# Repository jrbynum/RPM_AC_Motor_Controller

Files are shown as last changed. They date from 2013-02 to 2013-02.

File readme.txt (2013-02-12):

RPM AC Motor Controller

This is an Arduino based motor controller that uses a reflective optical sensor to calculate rpm and an LM135
to compute temperature. It uses the PID library to compute feedback. RPM and Temperature are displayed on an LCD. 

A zero crossing circuit and triac are used to control the set RPM which is based upon a 10K pot. The circuit 
can also be controlled using a pwm input. This input could be used from Mach3.

11/02/2013 - Added an Eagle Schematic and Board layout for an Arduino shield that will be used for development.

Rusty Bynum
jrbynum@shaw.ca

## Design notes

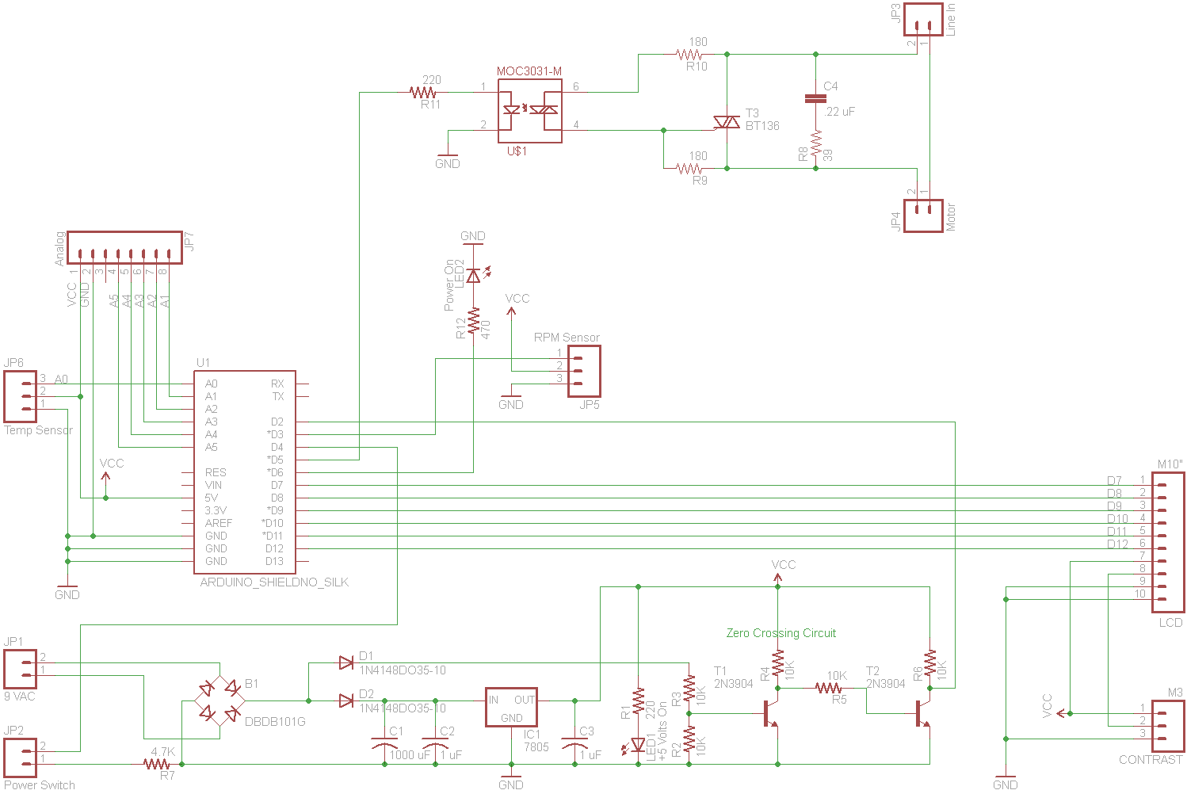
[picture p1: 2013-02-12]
Schematic/Arduino AC Motor Control Shield.png

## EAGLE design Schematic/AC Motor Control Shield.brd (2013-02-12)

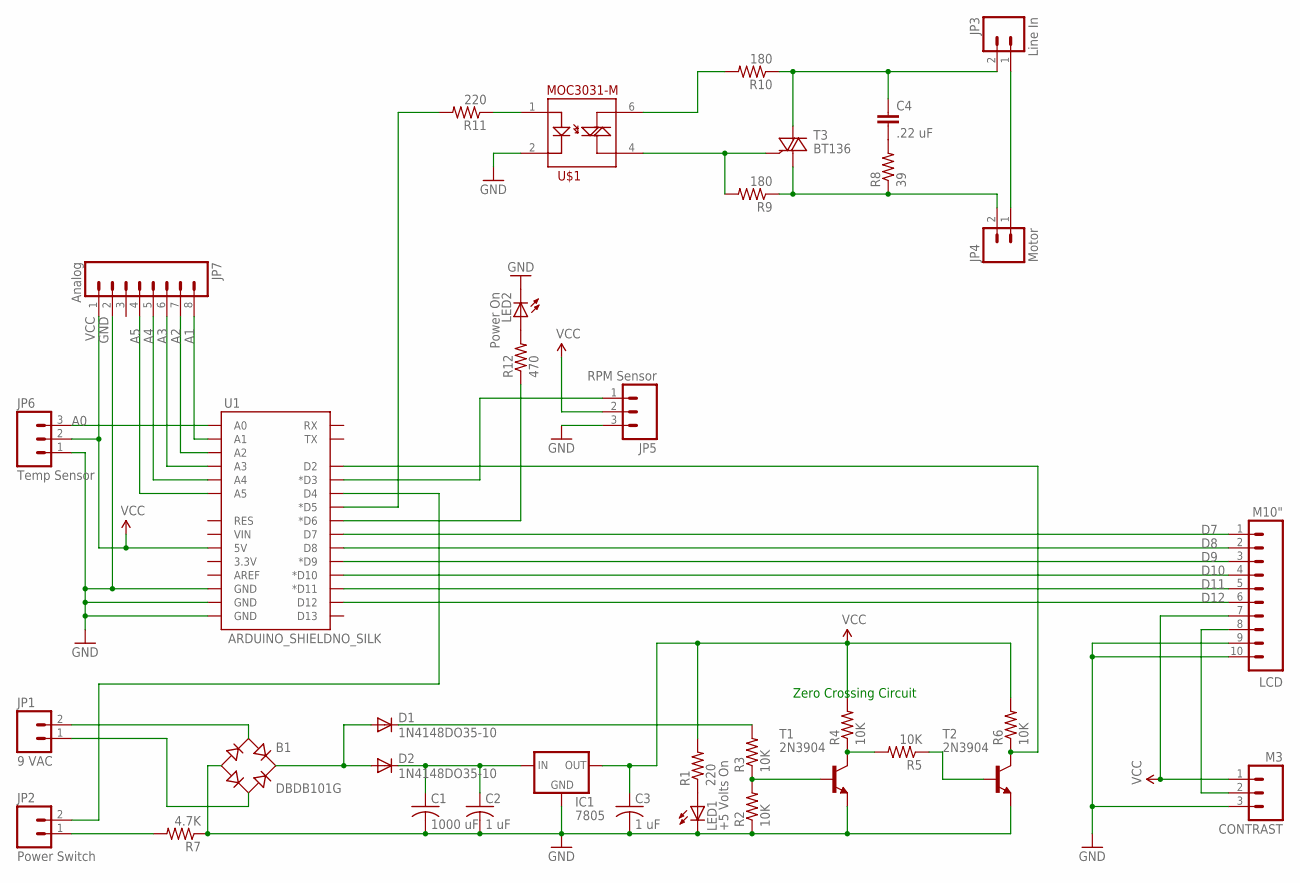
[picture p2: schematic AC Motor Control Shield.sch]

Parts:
B1: DBDB101G; DB
C1: 1000 uF; C050-035X075
C2, C3: 1 uF; C050-035X075
C4: .22 uF; CAP-PTH-LARGE
CONTRAST: M3; 1X03
D1, D2: 1N4148DO35-10; DO35-10
IC1: 7805; TO-220-ALT
JP1: 9 VAC; SCREWTERMINAL-5MM-2
JP2: Power Switch; 1X02
JP3: Line In; SCREWTERMINAL-5MM-2
JP4: Motor; SCREWTERMINAL-5MM-2
JP5: RPM Sensor; 1X03
JP6: Temp Sensor; 1X03
JP7: Analog; 1X08
LCD: M10"; 1X10
LED1: +5 Volts On; LED5MM
LED2: Power On; LED5MM
R1, R11: 220; 0207/10
R2, R3, R4, R5, R6: 10K; 0207/10
R7: 4.7K; 0207/10
R8: 39; AXIAL-0.6
R9, R10: 180; AXIAL-0.6
R12: 470; 0207/10
T1, T2: 2N3904; TO92
T3: BT136; TO220AB
U1: ARDUINO_SHIELDNO_SILK; DUEMILANOVE_VIAS
U$1: MOC3031-M; DIL06

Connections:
A0: JP6.3, U1.A0
A1: JP7.8, U1.A1
A2: JP7.7, U1.A2
A3: JP7.6, U1.A3
A4: JP7.5, U1.A4
A5: JP7.4, U1.A5
D7: LCD.1, U1.D7
D8: LCD.2, U1.D8
D9: LCD.3, U1.D9 (*D9)
D10: LCD.4, U1.D10 (*D10)
D11: LCD.5, U1.D11 (*D11)
D12: LCD.6, U1.D12
GND: B1.-, C1.2, C2.2, C3.2, CONTRAST.3, IC1.GND, JP5.3, JP6.1, JP7.2, LCD.9, LCD.10, LED1.K (C), LED2.K (C), R2.1, R7.1, T1.3 (E), T2.3 (E), U1.GND@0 (GND), U1.GND@1 (GND), U1.GND@2 (GND), U$1.2
unnamed: B1.AC2, JP1.1
unnamed: B1.AC1, JP1.2
unnamed: R5.1, T2.2 (B)
unnamed: B1.+, D1.A, D2.A
unnamed: D1.C, R3.2
unnamed: C1.1, C2.1, D2.C, IC1.IN
unnamed: JP2.1, R7.2
unnamed: LED1.A, R1.1
unnamed: R2.2, R3.1, T1.2 (B)
unnamed: R4.1, R5.2, T1.1 (C)
unnamed: R6.1, T2.1 (C), U1.D2
unnamed: JP2.2, U1.D4
unnamed: JP3.1, JP4.1
unnamed: C4.2, R8.P$2 (2)
unnamed: C4.1, JP3.2, R10.P$1 (1), T3.2 (A2)
unnamed: JP4.2, R8.P$1 (1), R9.P$1 (1), T3.1 (A1)
unnamed: R9.P$2 (2), T3.3 (G), U$1.4
unnamed: R10.P$2 (2), U$1.6
unnamed: R11.1, U$1.1
unnamed: R11.2, U1.D5 (*D5)
unnamed: JP5.1, U1.D3 (*D3)
unnamed: CONTRAST.2, LCD.8
unnamed: LED2.A, R12.2
unnamed: R12.1, U1.D6 (*D6)
VCC: C3.1, CONTRAST.1, IC1.OUT, JP5.2, JP6.2, JP7.1, LCD.7, R1.2, R4.2, R6.2, U1.5V

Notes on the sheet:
Zero Crossing Circuit

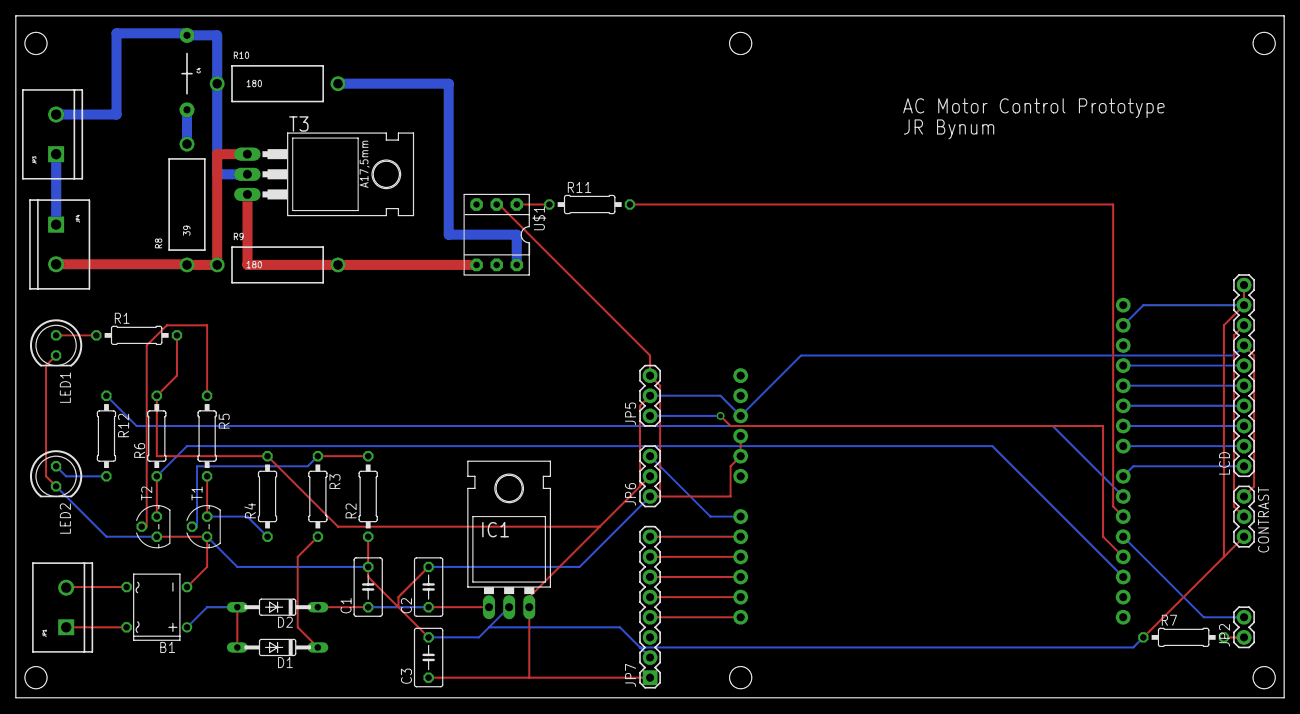
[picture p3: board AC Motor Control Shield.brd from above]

Board: 2 copper layers, 160.0 x 86.0 mm, 36 parts (0 on the bottom side), 38 nets.

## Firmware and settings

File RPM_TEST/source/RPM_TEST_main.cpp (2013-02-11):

/*************************************************************
project:  PID AC Motor Speed Controller
author:  JR Bynum
description: Main Module - All control is done from here
*************************************************************/
#define  MAIN
#include "RPM_TEST_main.h"

// initialize the LCD library with the numbers of the interface pins
// initialized here ans declared extern in any other .cpp modules in which it is used
LiquidCrystal lcd(12, 11, 7, 8, 9, 10);

void setup() {                

//initialize global variables
init_global_vars();
//setup the pins to match the hardware
setup_inputs_outputs();
//setup and start 1ms timer - our heartbeat
setup_heartbeat_timer();
//initialized the LCD
init_lcd();


#ifdef DEBUG
   Serial.begin(115200);
  // Print a startup message
  Serial.println("I am Alive!");
    /* Configure the debug pin as output */  
  pinMode(debug_pin, OUTPUT);   
  
  #endif


}
//**********************************************************************************
// Main loop - all tasks are timed my the 1 ms timer interrupt 
// Tasks are setup using a task structure which includes a counter, a time, and a flag
// Current Tasks are:
//
// Temperature is calculated every 1 second
// RPM is calulated every 250 ms
//To do - 
// add PID
// add Triac Control
//***********************************************************************************

void loop() {


				//Check to see if its time to compute the temperature 
				//temp sensor is a LM135
				if(TEMPtask.timerfired == true )  //temperature measurement
				{
						TEMPtask.timerfired = false;				

						if(digitalRead(powerOn)) // power on switch is off - pin is high
						{
								lcd.setCursor(0,0);
								lcd.print ("Power Off");

						}
						lcd.setCursor(0,1);
						lcd.print("Temp: ");
						lcd.print(read_tempsensor());
				}
				//Check to see if its time to compute the RPM measurement
				//Sensor is an 
				if (RPMtask.timerfired == true)
				{
						RPMtask.timerfired = false;			
	
						if(!digitalRead(powerOn)) //power switch is in - pin is low
						{
								calc_rpm();
						}
				
				}
}

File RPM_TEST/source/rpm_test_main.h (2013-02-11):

//-------------------------------------------------------------------
#ifndef __rpm_test_main_H__
#define __rpm_test_main_H__
//-------------------------------------------------------------------
 
#include <arduino.h>
// include the library code:
#include <LiquidCrystal.h>

 
//-------------------------------------------------------------------
 
//-------------------------------------------------------------------
 
// Put yout declarations here
//#define DEBUG 1 // comment out to get rid of debuging code
 #define rpm_sensor 3 
 #define powerOn 4
 #define debug_pin 2
 #define NOISE 125
 #define RPMAVG 250
 #define TEMPSENSOR1 0
 
 struct opsys {
	
			bool timerfired;
			unsigned long timer;
			unsigned long counter;
  };
 
 //use EXTERN for global vaiable - must initialize them in init_vars function
 #ifdef MAIN
#define EXTERN /* nothing */
#else
#define EXTERN extern
#endif /* DEFINE_VARIABLES */
 
 //operating system stuff
 EXTERN opsys RPMtask;    //rpm measurement
 EXTERN opsys TEMPtask;  //temperature measurement
 
 EXTERN unsigned int rpmcount;
 EXTERN unsigned int rpm;
 EXTERN unsigned long timeold;
 
 
 //software timers
 EXTERN unsigned long  timer_calc_rpm;
 EXTERN volatile unsigned long timer_toggle_led;
 
 /* Timer2 reload value, globally available */  
EXTERN unsigned int tcnt2;  
  
/* Toggle HIGH or LOW digital write */  
EXTERN int toggle;  
EXTERN int toggleled;  

//EXTERN LiquidCrystal lcd;

//--------------------------------------------------------------------
//Functions declared outside of MAIN in another file
//--------------------------------------------------------------------
//defined in - diagnostics.cpp
extern void debug();
//defined in - startup.cpp
extern void init_global_vars();
extern  void setup_inputs_outputs();
extern void setup_heartbeat_timer();
extern void init_lcd();
extern void setup_operating_system();

//defined in - calculations.cpp
extern long calc_rpm();
extern float read_tempsensor();
//defined in isrs.cpp
extern void rpm_function() ;

//-------------------------------------------------------------------
//End Functions Declerations
//--------------------------------------------------------------------
 
//===================================================================
// -> DO NOT WRITE ANYTHING BETWEEN HERE...
// 		This section is reserved for automated code generation
// 		This process tries to detect all user-created
// 		functions in main_sketch.cpp, and inject their
// 		declarations into this file.
// 		If you do not want to use this automated process,
//		simply delete the lines below, with "&MM_DECLA" text
//===================================================================
//---- DO NOT DELETE THIS LINE -- @MM_DECLA_BEG@---------------------
void loop();
void setup();
//---- DO NOT DELETE THIS LINE -- @MM_DECLA_END@---------------------
// -> ...AND HERE. This space is reserved for automated code generation!
//===================================================================
 
 
//-------------------------------------------------------------------
#endif
//-------------------------------------------------------------------
 

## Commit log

2013-02-11 Initial Create
    Basic Code - setup to use MariaMole IDE for the Arduino.
    TCRT5000 Reflective Optical Sensor implemented
    LM135 Tempertaure Sensor implemented
    Lots left todo!
2013-02-12 Intial prototype schematic for development
    [AC Motor Control Shield.brd, AC Motor Control Shield.sch]

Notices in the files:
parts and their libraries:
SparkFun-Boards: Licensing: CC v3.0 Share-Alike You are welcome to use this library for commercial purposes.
